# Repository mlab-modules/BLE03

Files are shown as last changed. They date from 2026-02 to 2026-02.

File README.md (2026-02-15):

# BLE03 - CC3301-based BLE 5.4 / Wi-Fi 6 Module 

BLE03 is an MLAB Bluetooth and Wifi connectivity module built around the TI CC3301. It provides 2.4 GHz Wi-Fi 6 (802.11ax) and Bluetooth Low Energy 5.4 as a companion IC intended to be controlled by an external MCU/MPU host over SDIO (4-bit) (or SPI on the chip), plus UART HCI for BLE.  

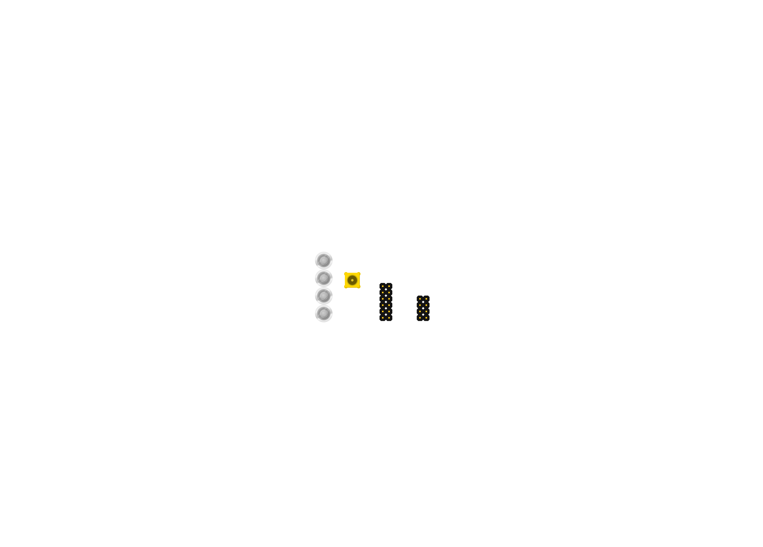
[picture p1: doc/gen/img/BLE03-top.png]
BLE03 top view

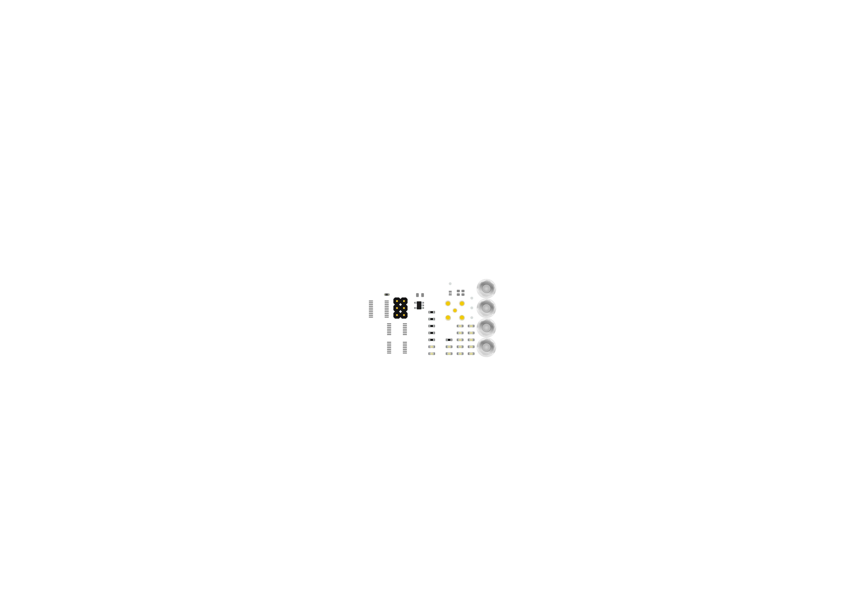
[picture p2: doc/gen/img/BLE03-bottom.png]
BLE03 bottom view


## Key features

* **Wi-Fi**
  * 2.4 GHz Wi-Fi 6 (802.11ax), 20 MHz, 1×1 SISO 
  * Backward compatibility: 802.11 a/b/g/n/ac 
  * HW crypto: WPA2 / WPA3 
  * Up to +20.5 dBm TX power (integrated PA) 
  * Application throughput up to 50 Mbps
* **Bluetooth**
  * Bluetooth Low Energy 5.4 (CC3301) 
  * HCI transport via UART (or shared SDIO on the chip) 
* **Module implementation highlights**
  * Onboard 1.8 V regulator (MIC5504-1.8) fed from 3.3 V input 
  * Bidirectional level shifting to 3.3 V logic using TXS0104 / TXS0108 for host interfaces 
  * 2.4 GHz RF routed through a front-end with an SAW filter to an MCX coax antenna connector

## Hardware overview

The design follows CC3301 reference integration principles: external 40 MHz fast clock (XTAL), external 32.768 kHz slow clock, SDIO host interface, and RF port brought out to an external antenna connector.  

### Power

* **Input**: `3.3V` to module power header J2 
* **Onboard regulation**: MIC5504-1.8 generates `+1V8` for CC3301 domains and level shifters 
* **CC3301 rails (chip-level reference)**:
  * VMAIN / VDDA / VIO / VPP: 1.8 V nominal 
  * VPA: 3.3 V nominal (PA supply) 

**Power-up sequencing note (chip requirement):** all supplies must be stable before releasing `nRESET` high; keep `nRESET` low at least 10 µs after supplies stabilize. 

## Interfaces

### SDIO host (Wi-Fi)

CC3301 supports 4-bit SDIO (up to 52 MHz high speed) or SPI at the chip level. BLE03 breaks out the SDIO signals through a level shifter to the host connector.  

### UART HCI (BLE)

BLE HCI UART is routed through a level shifter to the host connector:

* `UART_TX`, `UART_RX`, `UART_CTS`, `UART_RTS`  

## Software integration notes

BLE03 is a controller IC: the host is responsible for overall application logic. Typical integration:

* **Wi-Fi**: host communicates over SDIO and runs the networking stack (Linux/RTOS use-cases are explicitly targeted by CC330x). 
* **BLE**: host uses UART HCI to a BLE stack/controller interface.

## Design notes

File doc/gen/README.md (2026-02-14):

# PCB

Board size: N/AxN/A mm (N/AxN/A inches)

- This is the size of the rectangle that contains the board
- Thickness: 1.6 mm (63 mils)
- Material: FR4
- Finish: HAL
- Layers: 2
- Copper thickness: 35 µm

Solder mask: TOP / BOTTOM

- Color: Green

Silk screen: TOP / BOTTOM

- Color: White

# Important sizes

Clearance: 0.2 mm (8 mils)

Track width: N/A mm (N/A mils)

- By design rules: 0.0 mm (0 mils)

Drill: 1.0 mm (39 mils)

- Vias: N/A mm (N/A mils) [Design: 0.4 mm (16 mils)]
- Pads: 1.0 mm (39 mils)
- The above values are real drill sizes, they add 0.1 mm (4 mils) to plated holes (PTH)

Via: N/A/N/A mm (N/A/N/A mils)

- By design rules: 0.5/0.3 mm (20/12 mils)
- Micro via: yes [0.2/0.1 mm (8/4 mils)]
- Buried/blind via: yes
- Total: 0 (thru: 0 buried/blind: 0 micro: 0)

Outer Annular Ring: 0.26 mm (10 mils)

- By design rules: 0.26 mm (10 mils)

Eurocircuits class: 4A
- Using min drill 1.0 mm for an OAR of 0.26 mm

# General stats

Components count: (SMD/THT)

- Top: 0/7 (THT)
- Bottom: 31/1 (SMD + THT)

Defined tracks:

Used tracks:

Defined vias:

Used vias:

Holes (excluding vias):

- 0.89 mm (35 mils) (26)
- 1.5 mm (59 mils) (1)
- 1.7 mm (67 mils) (4)
- 3.0 mm (118 mils) (4)

Oval holes:

Drill tools (including vias and computing adjusts and rounding):

- 1.0 mm (39 mils) (26)
- 1.6 mm (63 mils) (1)
- 1.8 mm (71 mils) (4)
- 3.1 mm (122 mils) (4)

Solder paste stats:

Using a paste with 87.75 % alloy, that has an specific gravity for the alloy of 7.4 g/cm³
and 1.0 g/cm³ for the flux. This paste has an specific gravity of  4.15 g/cm³.

The stencil thickness is  0.12 mm.

| Side | Pads with paste | Area [mm²] | Paste [g] |
|---|---|---|---|
| Total  | 105 | 71.72 | 0.36 |

Note: this is just an approximation to the theoretical value. Margins of the solder mask and waste aren't computed.

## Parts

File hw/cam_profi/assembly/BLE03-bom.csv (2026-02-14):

Component | Description | Part | References | Value | Footprint | Quantity Per PCB | Datasheet | ust_id | sim.pins
1 | Unpolarized capacitor, small symbol | C_Small | C9C10 | 6.8pF | C_0603_1608Metric | 2 | ~
2 | Unpolarized capacitor | C_Small | C15 | 10pF | C_0603_1608Metric | 1 | ~
3 | Unpolarized capacitor, small symbol | C_Small | C1C2C3C4C5C12C13 | 0.1uF | C_0603_1608Metric | 7 | ~
4 | Unpolarized capacitor | C | C14 | 1uF | SMD-0603 | 1 | ~ | 5c70984812875079b91f8bc2
5 | Unpolarized capacitor, small symbol | C_Small | C6C7C8 | 1.0uF | C_0603_1608Metric | 3 | ~
6 | Unpolarized capacitor | C | C11 | 10uF | C_0603_1608Metric | 1 | ~
7 |  | D_ZENER | D2 | BZX585-B5V6.115 | D_SOD-523 | 1 |  | 60879d38128750769ee58e48
8 | Light emitting diode | LED | D1 | LED | LED_0805_2012Metric | 1 | ~ |  | 1=K 2=A
9 | 2x03 2.54 mm pitch header, 2 pins next to each other are connected | HEADER_2x03_PARALLEL | J2 | 3.3-5V | Straight_2x03 | 1
10 | coaxial connector (BNC, SMA, SMB, SMC, Cinch/RCA, LEMO, ...) | Conn_Coaxial | J4 | Conn_Coaxial | MCX | 1 | ~
11 | 2x06 2.54 mm pitch header, 2 pins next to each other are connected | HEADER_2x06_PARALLEL | J5 | HEADER_2x06_PARALLEL | Straight_2x06 | 1
12 | 2x04 2.54 mm pitch header, 2 pins next to each other are connected | HEADER_2x04_PARALLEL | J3 | JUMP_5X2 | Straight_2x04 | 1
13 | Resistor, small symbol | R_Small | R1 | 150 | R_0603_1608Metric | 1 | ~
14 |  | R-Device | R4 | 2k2 | R_0603_1608Metric | 1 | ~
15 |  | R-Device | R2R3R5 | 10k | R_0603_1608Metric | 3 | ~
16 |  | CC3301 | U1 | CC3301 | WQFN_JARSBR_TEX | 1 | https://www.ti.com/lit/gpn/cc3301
17 |  | LFB212G45CG1C187 | U6 | LFB212G45CG1C187 | Murata_C187 | 1 | https://pim.murata.com/asset/pim4/bandPassFilterBPF/LFB212G45CG1C187_PDF_BANDPASSFILTERBPF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
18 | 300mA Low-dropout Voltage Regulator, Vout 1.8V, Vin up to 5.5V, SOT-23 | MIC5504-1.8YM5 | U4 | MIC5504-1.8YM5 | SOT-23-5 | 1 | http://ww1.microchip.com/downloads/en/DeviceDoc/MIC550X.pdf
19 | Bidirectional level-shifting voltage translator, TSSOP-14 | TXS0104EPW | U2U3 | TXS0104EPW | TSSOP-14_4.4x5mm_P0.65mm | 2 | www.ti.com/lit/ds/symlink/txs0104e.pdf
20 | Bidirectional level-shifting voltage translator, TSSOP-20 | TXS0108EPW | U5 | TXS0108EPW | TSSOP-20_4.4x6.5mm_P0.65mm | 1 | www.ti.com/lit/ds/symlink/txs0108e.pdf
21 | 32.768kHz Crystal Oscillator (SPXO) | SG-3030CM | Y2 | LFSPXO009682 | Oscillator_SMD_SeikoEpson_SG210-4Pin_2.5x2.0mm | 1 | https://support.epson.biz/td/api/doc_check.php?mode=dl&lang=en&Parts=SG-3030CM
22 | 40MHz | Crystal_GND23 | Y1 | TZ3877AAA044 |  | 1 | ~

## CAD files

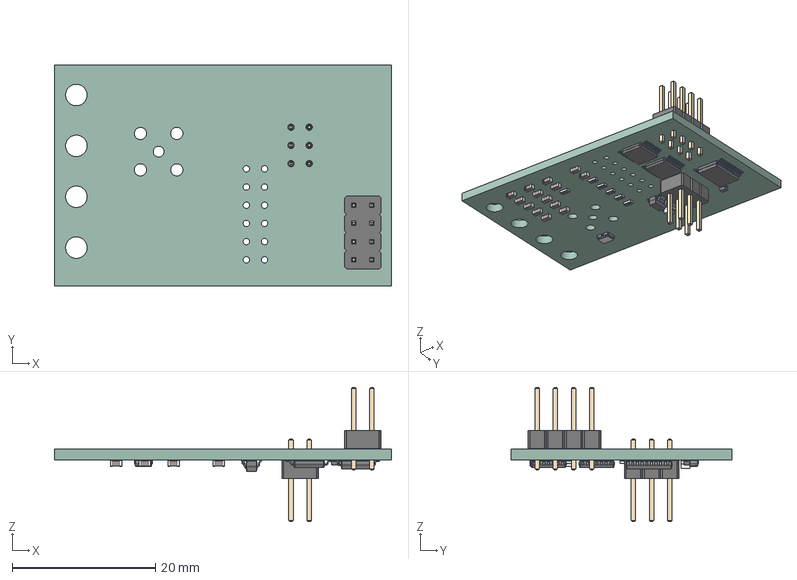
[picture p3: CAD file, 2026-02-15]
doc/gen/BLE03.step
47.0 x 30.9 x 18.8 mm
PinHeader_2x04_P2.54mm_Vertical
TSSOP-14_4.4x5mm_P0.65mm x 2
C_0603_1608Metric x 14
D_SOD-523
LED_0805_2012Metric
R_0603_1608Metric x 6
PinHeader_2x03_P2.54mm_Vertical
TSSOP-20_4.4x6.5mm_P0.65mm
SOT-23-5
Oscillator_SMD_SeikoEpson_SG210-4Pin_2.5x2.0mm
kibot_dzgkb_3j_PCB

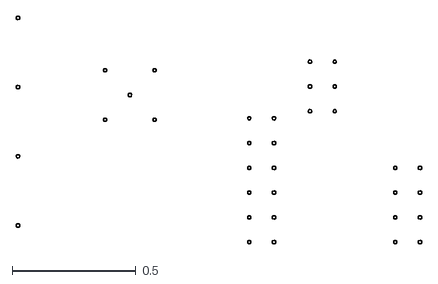
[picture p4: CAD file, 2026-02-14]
doc/gen/dxf/BLE03-F_Courtyard.dxf
1.64 x 0.919

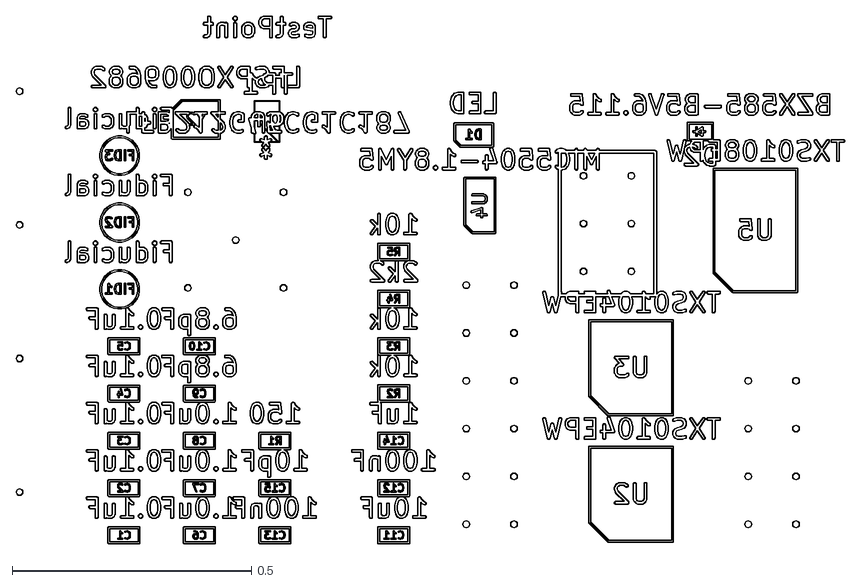
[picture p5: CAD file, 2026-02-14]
doc/gen/dxf/BLE03-B_Fab.dxf
1.73 x 1.10

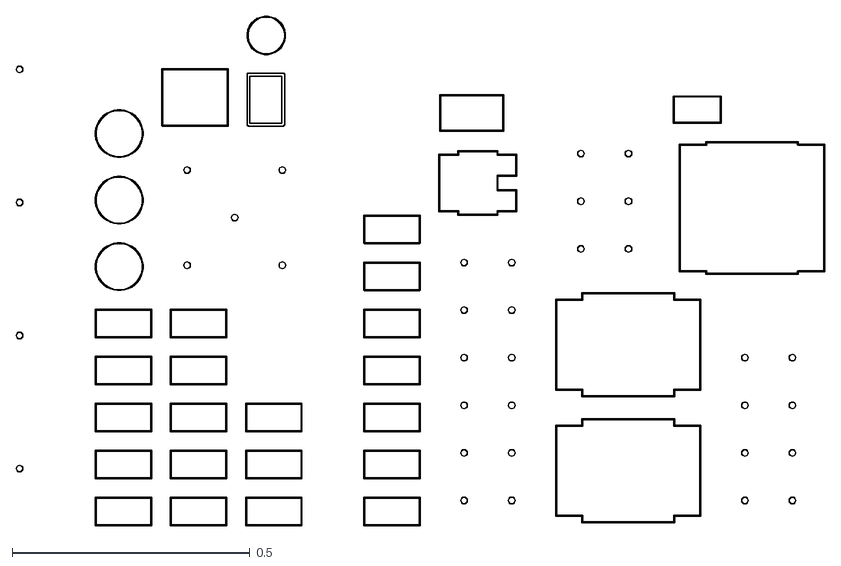
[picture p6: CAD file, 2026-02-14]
doc/gen/dxf/BLE03-B_Courtyard.dxf
1.70 x 1.07

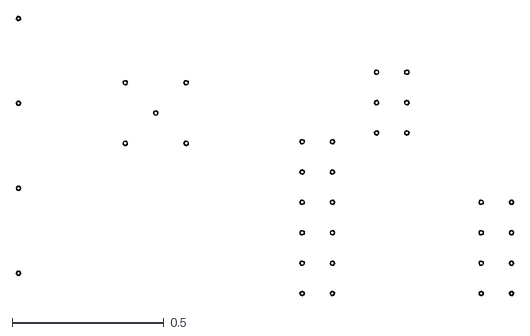
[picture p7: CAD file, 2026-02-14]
doc/gen/dxf/BLE03-F_Adhesive.dxf
1.64 x 0.919

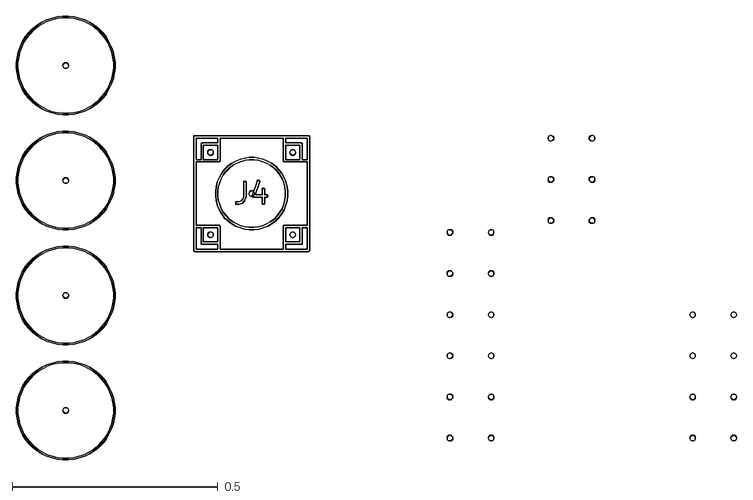
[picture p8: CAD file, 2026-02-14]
doc/gen/dxf/BLE03-F_Fab.dxf
1.75 x 1.08

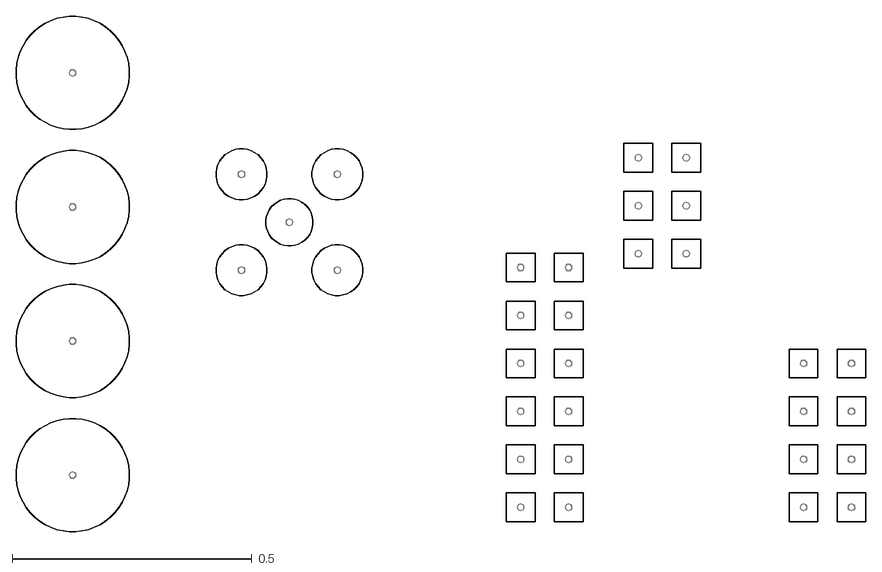
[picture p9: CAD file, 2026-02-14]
doc/gen/dxf/BLE03-F_Cu.dxf
1.77 x 1.07

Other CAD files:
doc/gen/dxf/BLE03-B_Cu.dxf
doc/gen/dxf/BLE03-B_Mask.dxf
doc/gen/dxf/BLE03-B_Paste.dxf
doc/gen/dxf/BLE03-B_Silkscreen.dxf
doc/gen/dxf/BLE03-F_Silkscreen.dxf

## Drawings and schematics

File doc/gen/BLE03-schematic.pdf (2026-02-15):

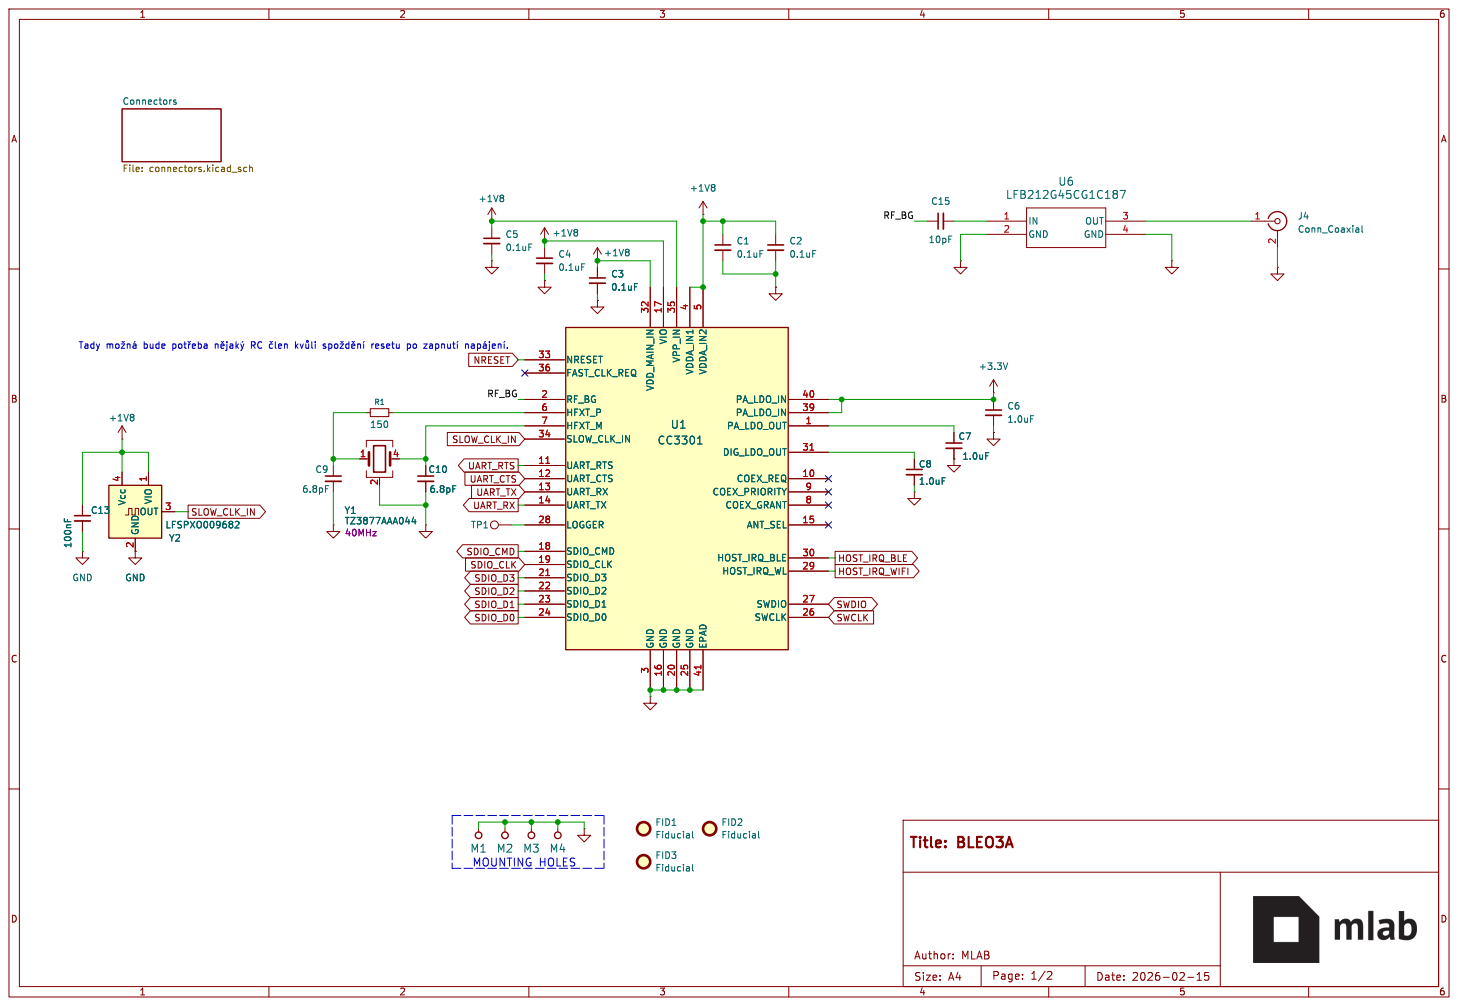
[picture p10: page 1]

Tady þÿmo~ná bude þÿpotYeba þÿnjaký RC þÿ

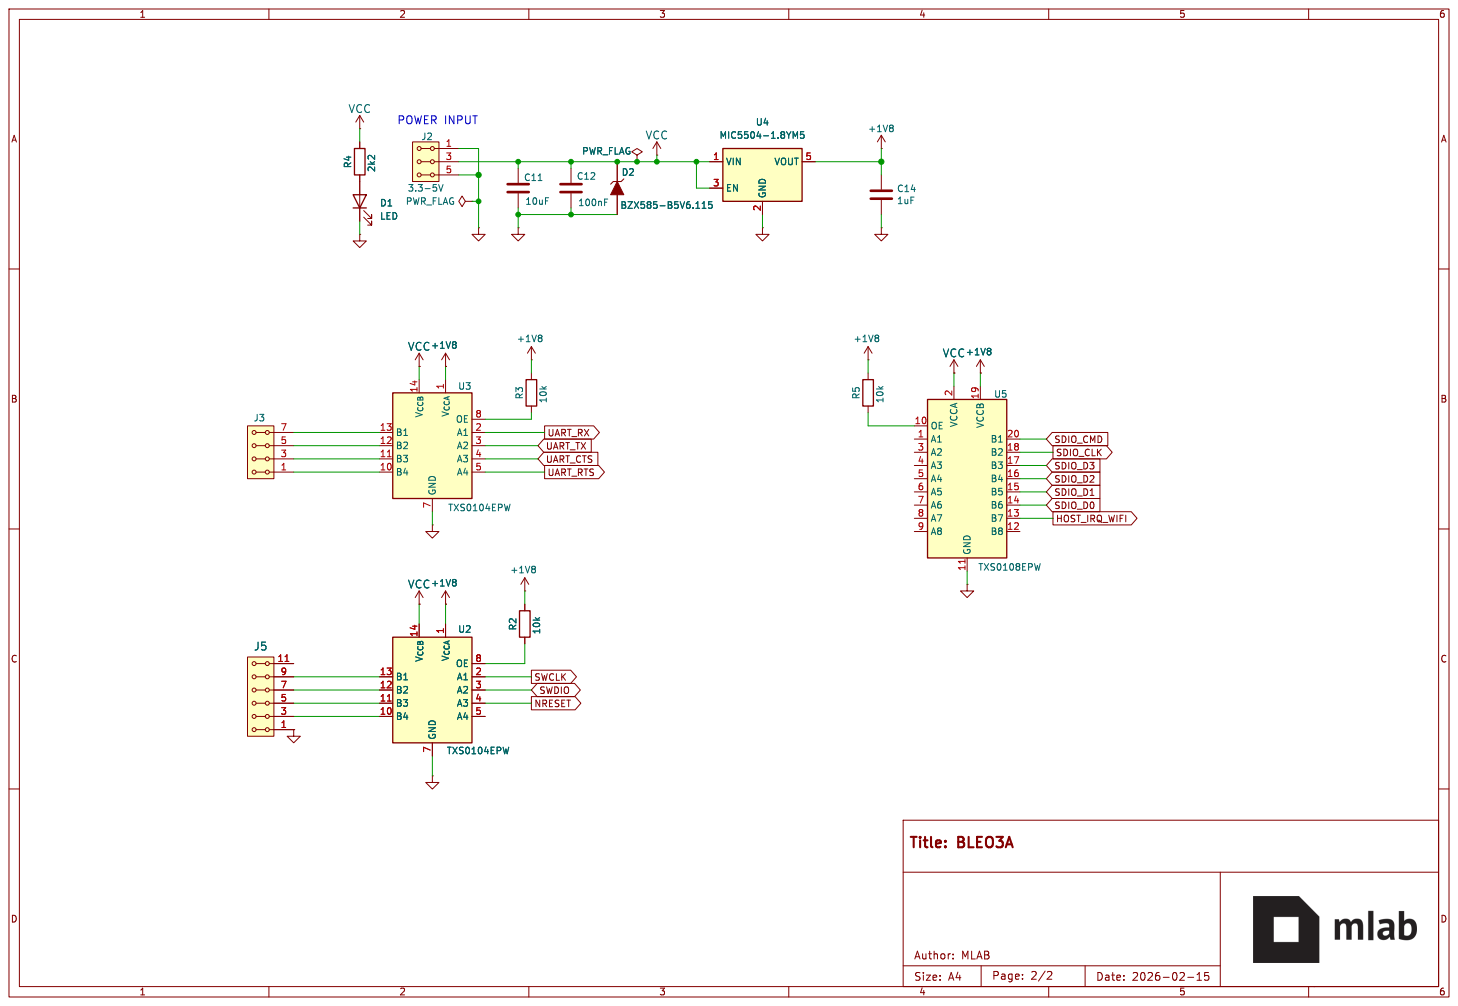
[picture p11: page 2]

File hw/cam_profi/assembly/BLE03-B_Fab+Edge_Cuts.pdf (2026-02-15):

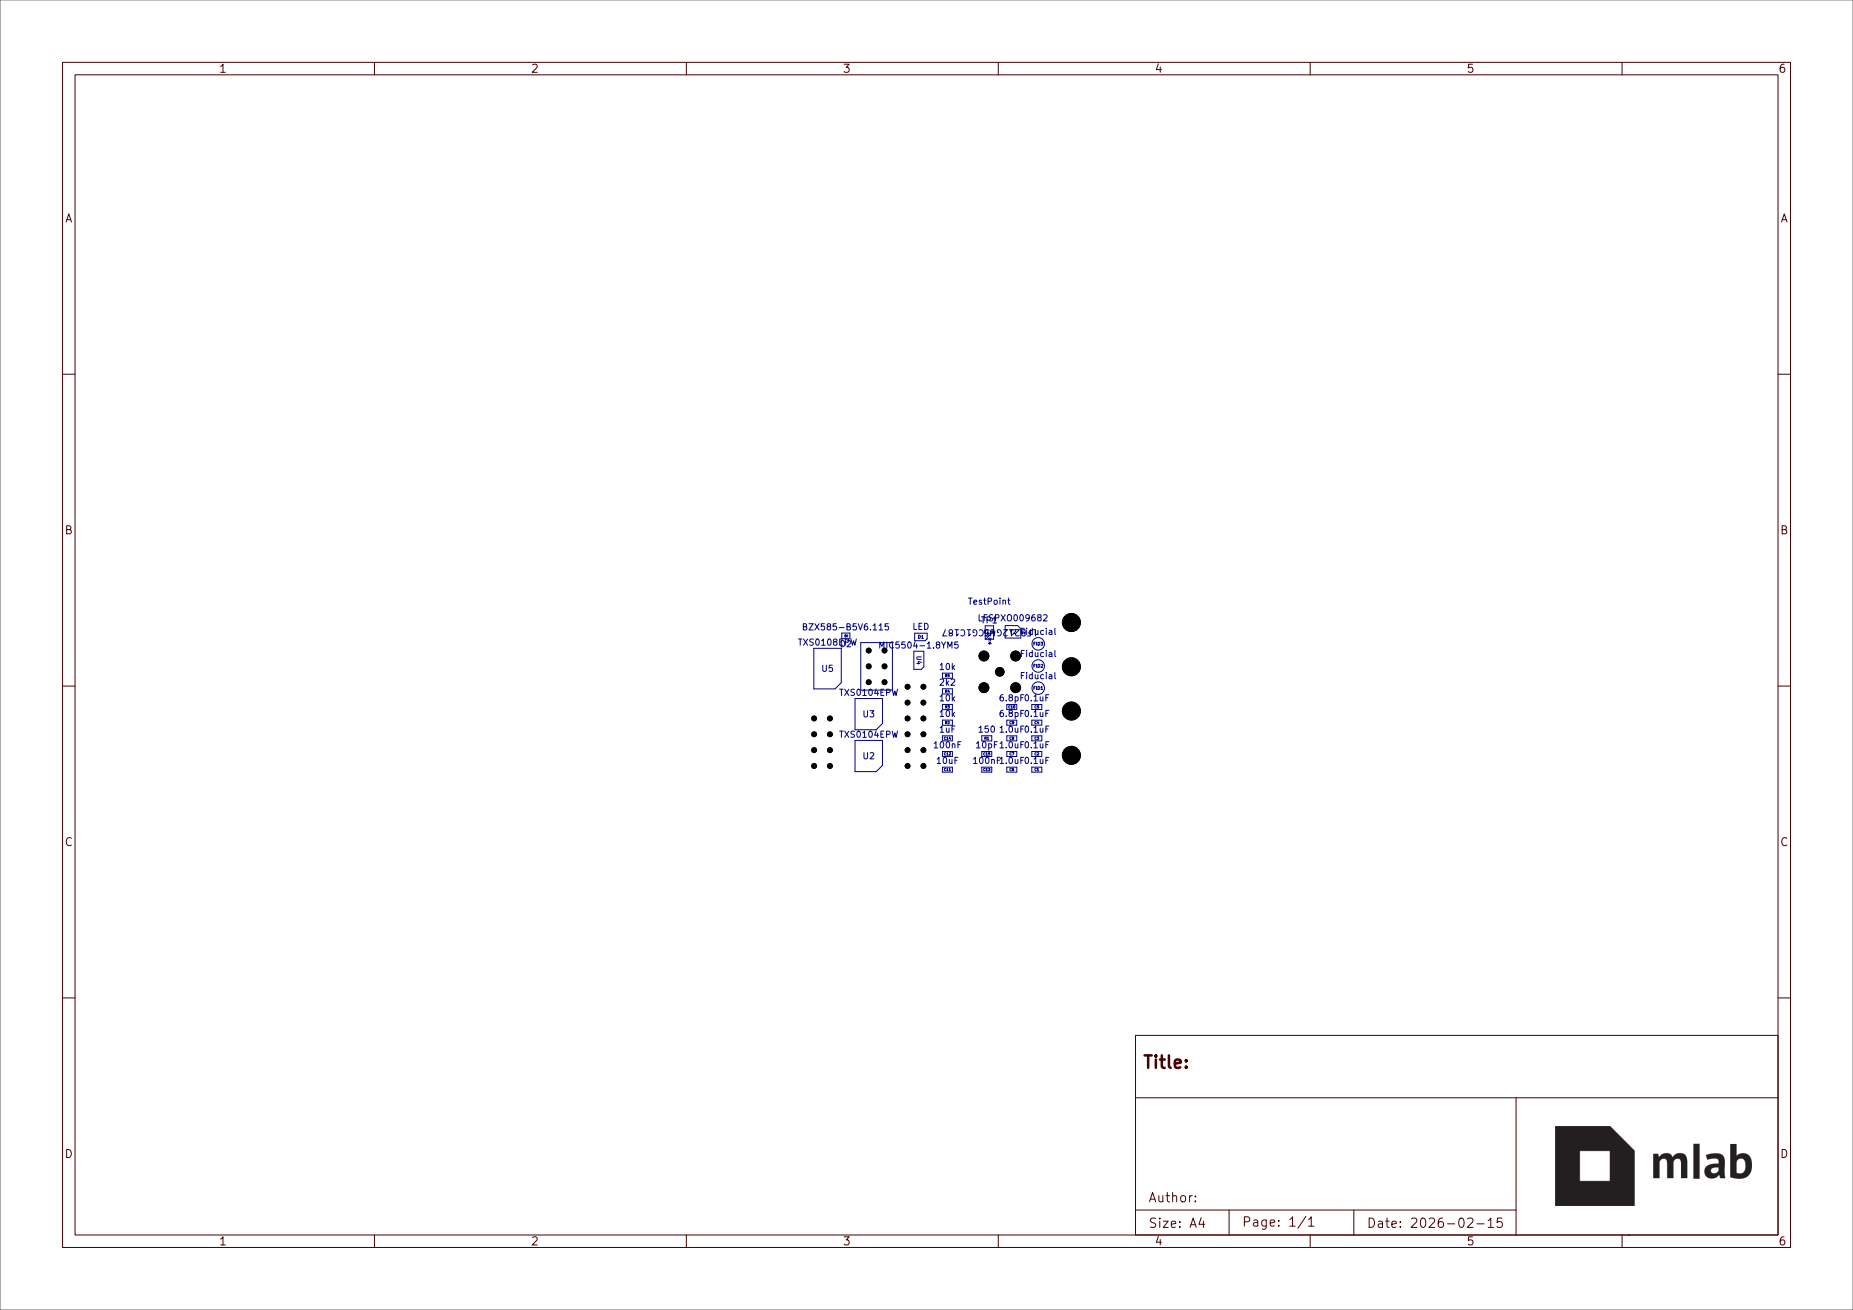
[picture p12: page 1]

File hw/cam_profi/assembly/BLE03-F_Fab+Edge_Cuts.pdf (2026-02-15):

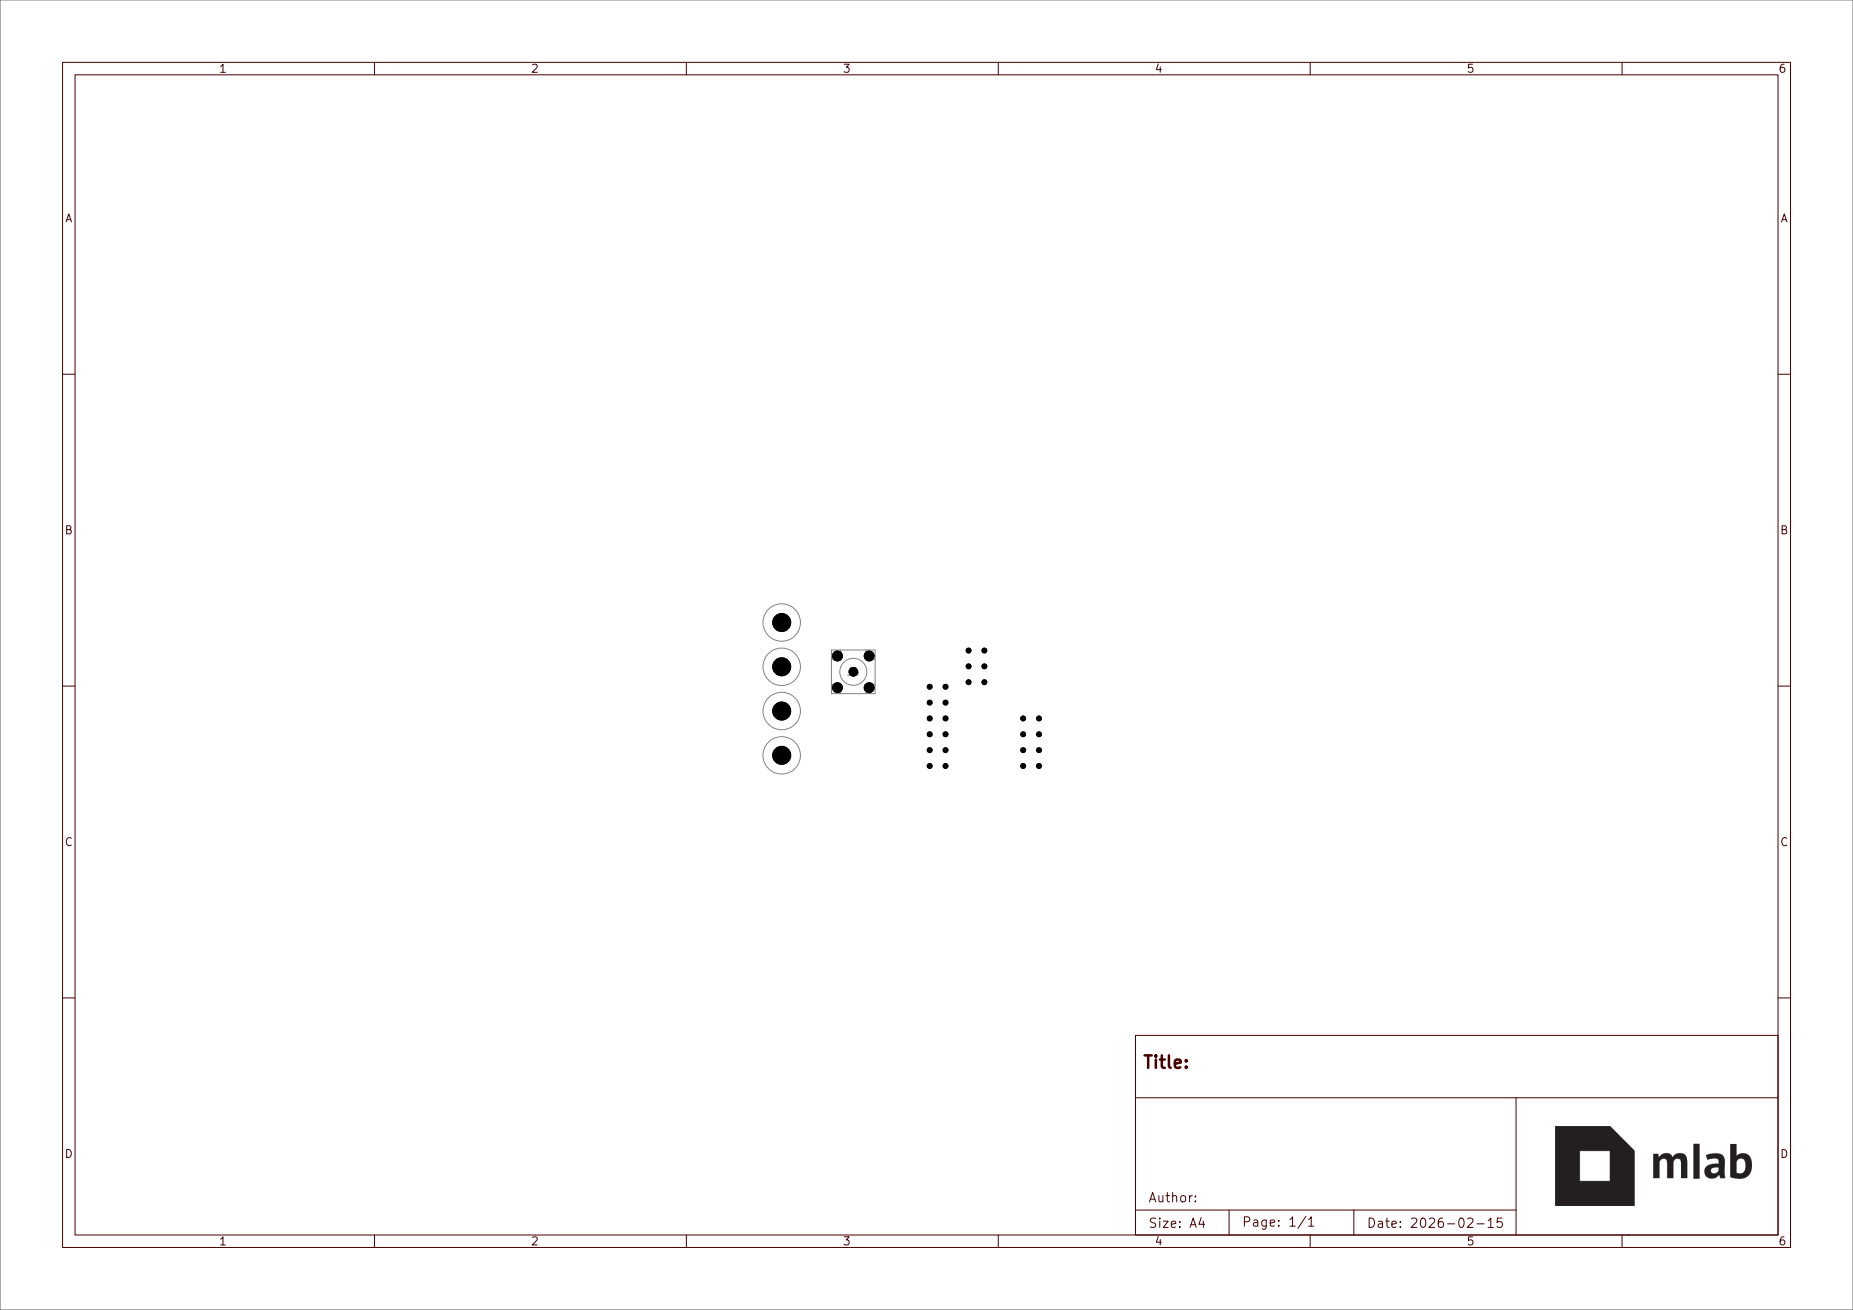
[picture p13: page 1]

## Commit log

2026-02-14 Adding KiCad project
    [BLE03.kicad_pcb, BLE03.kicad_sch, connectors.kicad_sch]
2026-02-14 Update github actions. Move KiCAD project to the correct directory.
    [BLE03.kicad_pcb, BLE03.kicad_sch, connectors.kicad_sch]
2026-02-14 Automatic update of KiCAD outputs
    [BLE03-B_Adhesive.dxf, BLE03-B_Courtyard.dxf, BLE03-B_Cu.dxf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]
2026-02-14 Change SAW filter to more available component type.
    [BLE03.kicad_pcb, BLE03.kicad_sch]
2026-02-15 Documentation cleanup.
    [BLE03.kicad_sch]
2026-02-15 Adding connectors and other components
    [BLE03.kicad_pcb, BLE03.kicad_sch, connectors.kicad_sch]
2026-02-17 Improving sch and adding RC filter for reset line
    [BLE03.kicad_pcb, BLE03.kicad_sch, connectors.kicad_sch]
2026-02-17 Update sch
    [connectors.kicad_sch]
